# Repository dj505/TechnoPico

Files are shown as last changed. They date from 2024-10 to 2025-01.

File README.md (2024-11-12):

# TechnoPico
## An advanced, customizable, and universal 18-button dance game controller
---
## **This project is ongoing! It's not quite ready yet.
Check in later to see when it's ready for release! You can keep up on [my Discord server](https://discord.gg/ctMByBy) or by messaging me directly.
---

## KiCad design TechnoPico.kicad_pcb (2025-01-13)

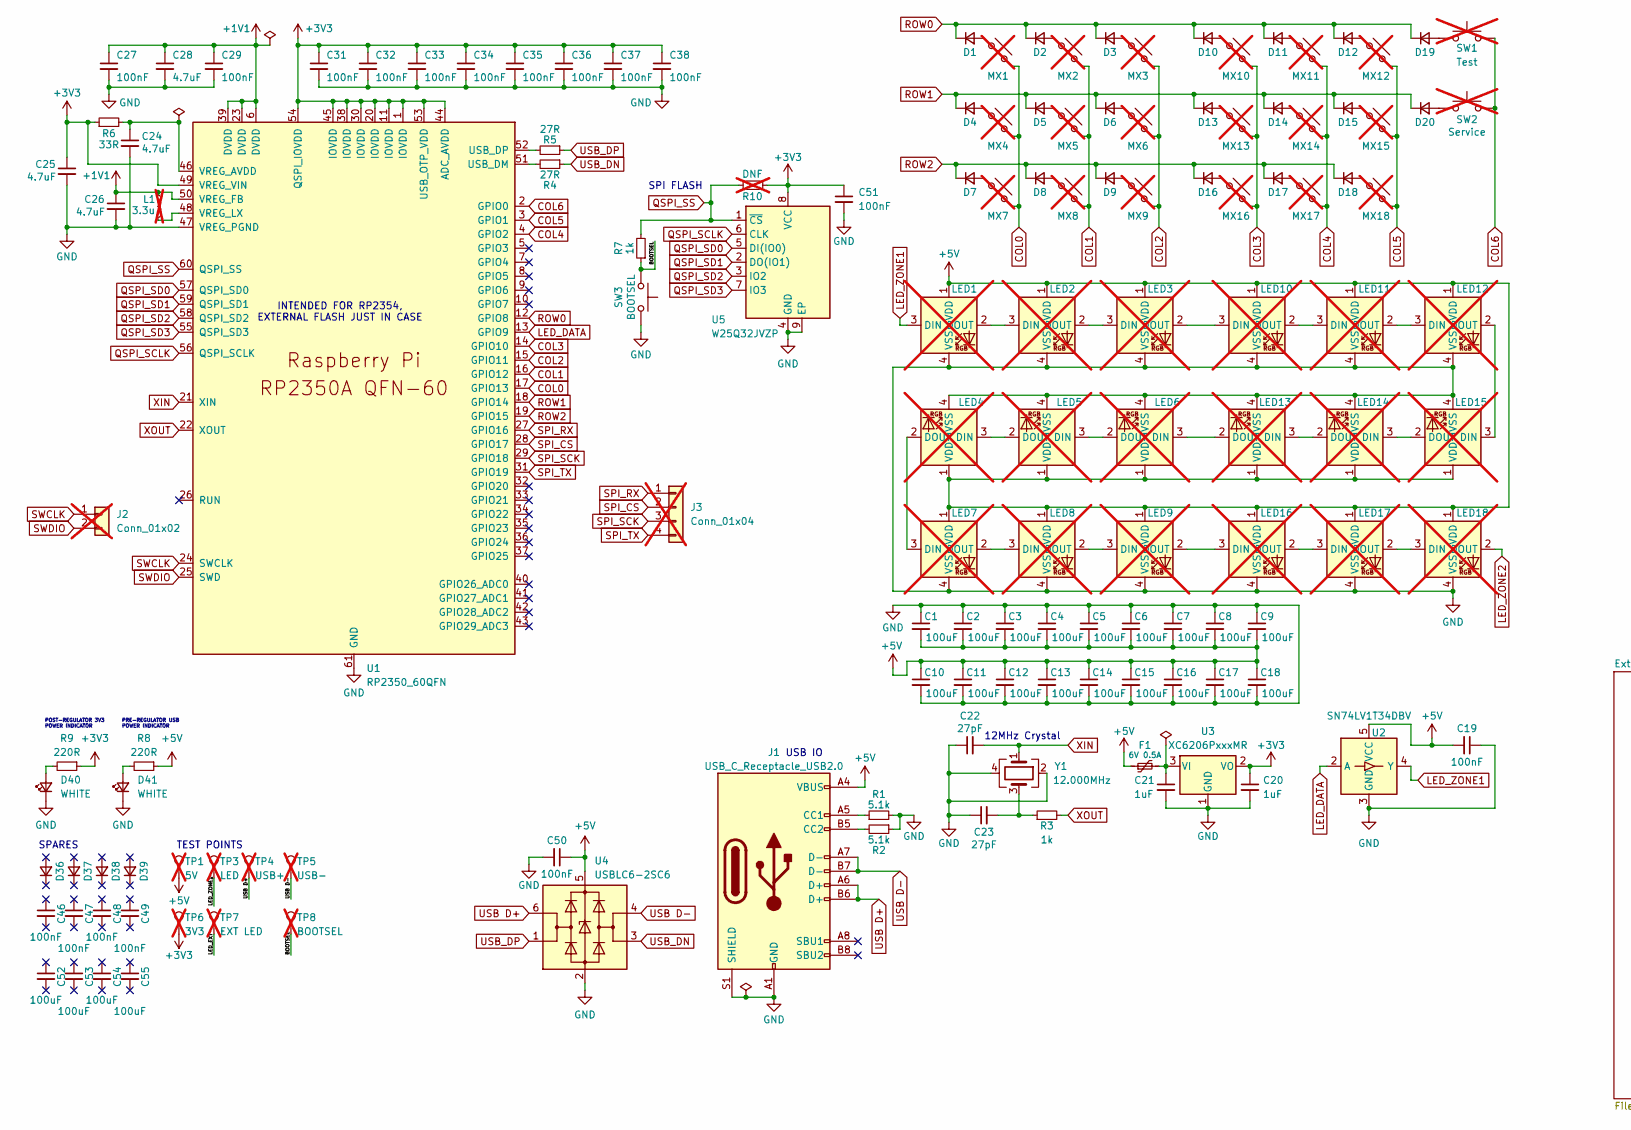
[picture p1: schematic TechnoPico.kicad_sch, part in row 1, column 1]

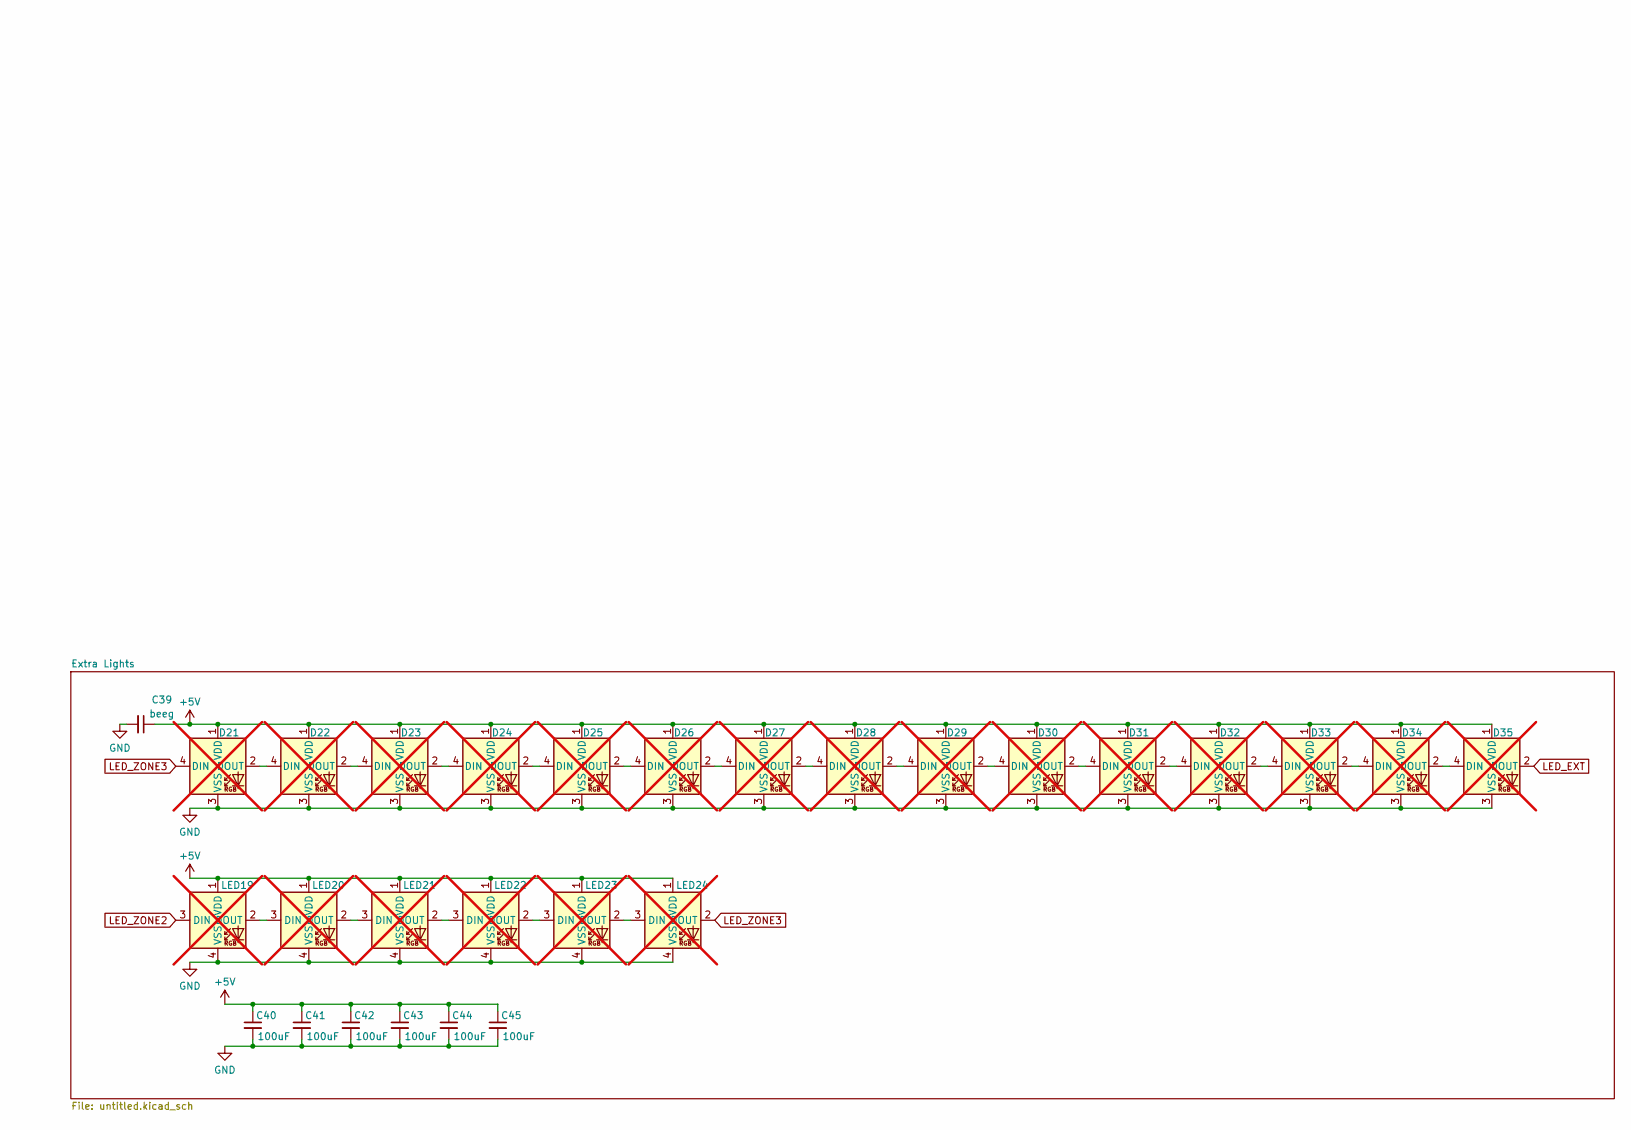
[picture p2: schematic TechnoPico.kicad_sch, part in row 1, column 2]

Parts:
C1, C2, C3, C4, C5, C6, C7, C8, C9, C10, C11, C12, C13, C14, C15, C16, C17, C18, C40, C41, C42, C43, C44, C45, C52, C53, C54, C55: 100uF; C_1206_3216Metric; LCSC C15008
C19, C27, C29, C31, C32, C33, C34, C35, C36, C37, C38, C46, C47, C48, C49, C50, C51: 100nF; C_0402_1005Metric; LCSC C1525
C20, C21: 1uF; C_0402_1005Metric; LCSC C52923
C22, C23: 27pF; C_0402_1005Metric; LCSC C1557
C24, C28: 4.7uF; C_0402_1005Metric; LCSC C274416
C25, C26: 4.7uF; C_0402_1005Metric_small_pads; LCSC C274416
C39: beeg; C_1206_3216Metric; LCSC C15008
D1, D2, D3, D4, D5, D6, D7, D8, D9, D10, D11, D12, D13, D14, D15, D16, D17, D18, D19, D20, D36, D37, D38, D39: SOD-123; D_SOD-123; LCSC C81598
D21, D22, D23, D24, D25, D26, D27, D28, D29, D30, D31, D32, D33, D34, D35: WS2812B; LED_WS2812B-2020_PLCC4_2.0x2.0mm; not fitted
D40, D41: WHITE; LED_0603_1608Metric; LCSC C2290
F1: 6V 0.5A; Fuse_0603_1608Metric; LCSC C69688
J1: USB_C_Receptacle_USB2.0; USB_C_Receptacle_G-Switch_GT-USB-7010ASV; LCSC C2988369
J2: Conn_01x02; PinSocket_1x02_P1.27mm_Vertical; not fitted
J3: Conn_01x04; PinHeader_1x04_P1.27mm_Vertical; not fitted
L1: 3.3u; L_pol_2016; not fitted
LED1, LED2, LED3, LED7, LED8, LED9, LED10, LED11, LED12, LED16, LED17, LED18: MX_SK6812MINI-E; LED_MX_6028R-ROT; not fitted
LED4, LED5, LED6, LED13, LED14, LED15: MX_SK6812MINI-E; LED_MX_6028R; not fitted
LED19, LED20, LED21, LED22, LED23, LED24: MX_SK6812MINI-E; LED_6028R; not fitted
MX1, MX2, MX3, MX4, MX5, MX6, MX7, MX8, MX9, MX10, MX11, MX12, MX13, MX14, MX15, MX16, MX17, MX18: MX_SW_HS; SW_MX_HS_CPG151101S11_1u; not fitted
R1, R2: 5.1k; R_0402_1005Metric; LCSC C25905
R3, R7: 1k; R_0402_1005Metric; LCSC C106235
R4, R5: 27R; R_0402_1005Metric; LCSC C2909343
R6: 33R; R_0402_1005Metric; LCSC C138002
R8, R9: 220R; R_0402_1005Metric; LCSC C112291
R10: DNF; R_0402_1005Metric_Pad0.72x0.64mm_HandSolder; not fitted
SW1: Test; SW_Tactile_SPST_Angled_PTS645Vx39-2LFS; not fitted
SW2: Service; SW_Tactile_SPST_Angled_PTS645Vx39-2LFS; not fitted
SW3: BOOTSEL; SW_Push_1P1T_XKB_TS-1187A; LCSC C318884
TP1: 5V; TestPoint_Pad_D1.0mm; not fitted
TP3: LED; TestPoint_Pad_D1.0mm; not fitted
TP4: USB+; TestPoint_Pad_D1.0mm; not fitted
TP5: USB-; TestPoint_Pad_D1.0mm; not fitted
TP6: 3V3; TestPoint_Pad_D1.0mm; not fitted
TP7: EXT LED; TestPoint_Pad_D1.0mm; not fitted
TP8: BOOTSEL; TestPoint_Pad_D1.0mm; not fitted
U1: RP2350_60QFN; RP2350-QFN-60-1EP_7x7_P0.4mm_EP3.4x3.4mm_ThermalVias; LCSC C42411118
U2: SN74LV1T34DBV; SOT-23-5; LCSC C100024
U3: XC6206PxxxMR; SOT-23-3; LCSC C5446
U4: USBLC6-2SC6; SOT-23-6; LCSC C2687116
U5: W25Q32JVZP; WSON-8-1EP_6x5mm_P1.27mm_EP3.4x4.3mm; LCSC C571260
Y1: 12.000MHz; Crystal_SMD_3225-4Pin_3.2x2.5mm; LCSC C20625731

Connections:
+1V1: C26.1, C27.1, C28.1, C29.1, L1.1, U1.6 (DVDD), U1.23 (DVDD), U1.39 (DVDD), U1.50 (VREG_FB)
+3V3: C20.1, C25.1, C31.1, C32.1, C33.1, C34.1, C35.1, C36.1, C37.1, C38.1, C51.1, R6.1, R9.1, R10.1, TP6.1, U1.1 (IOVDD), U1.11 (IOVDD), U1.20 (IOVDD), U1.30 (IOVDD), U1.38 (IOVDD), U1.44 (ADC_AVDD), U1.45 (IOVDD), U1.49 (VREG_VIN), U1.53 (USB_OTP_VDD), U1.54 (QSPI_IOVDD), U3.2 (VO), U5.8 (VCC)
+5V: C1.2, C2.2, C3.2, C4.2, C5.2, C6.2, C7.2, C8.2, C9.2, C10.1, C11.1, C12.1, C13.1, C14.1, C15.1, C16.1, C17.1, C18.1, C19.2, C39.1, C40.1, C41.1, C42.1, C43.1, C44.1, C45.1, C50.1, D21.1 (VDD), D22.1 (VDD), D23.1 (VDD), D24.1 (VDD), D25.1 (VDD), D26.1 (VDD), D27.1 (VDD), D28.1 (VDD), D29.1 (VDD), D30.1 (VDD), D31.1 (VDD), D32.1 (VDD), D33.1 (VDD), D34.1 (VDD), D35.1 (VDD), F1.1, J1.A4 (VBUS), J1.A9 (VBUS), J1.B4 (VBUS), J1.B9 (VBUS), LED1.1 (VDD), LED2.1 (VDD), LED3.1 (VDD), LED4.1 (VDD), LED5.1 (VDD), LED6.1 (VDD), LED7.1 (VDD), LED8.1 (VDD), LED9.1 (VDD), LED10.1 (VDD), LED11.1 (VDD), LED12.1 (VDD), LED13.1 (VDD), LED14.1 (VDD), LED15.1 (VDD), LED16.1 (VDD), LED17.1 (VDD), LED18.1 (VDD), LED19.1 (VDD), LED20.1 (VDD), LED21.1 (VDD), LED22.1 (VDD), LED23.1 (VDD), LED24.1 (VDD), R8.1, TP1.1, U2.5 (VCC), U4.5 (VBUS)
/BOOTSEL: R7.1, SW3.1, TP8.1
COL0: MX1.2, MX4.2, MX7.2, U1.17 (GPIO13)
COL1: MX2.2, MX5.2, MX8.2, U1.16 (GPIO12)
COL2: MX3.2, MX6.2, MX9.2, U1.15 (GPIO11)
COL3: MX10.2, MX13.2, MX16.2, U1.14 (GPIO10)
COL4: MX11.2, MX14.2, MX17.2, U1.4 (GPIO2)
COL5: MX12.2, MX15.2, MX18.2, U1.3 (GPIO1)
COL6: SW1.2, SW2.2, U1.2 (GPIO0)
GND: C1.1, C2.1, C3.1, C4.1, C5.1, C6.1, C7.1, C8.1, C9.1, C10.2, C11.2, C12.2, C13.2, C14.2, C15.2, C16.2, C17.2, C18.2, C19.1, C20.2, C21.2, C22.1, C23.1, C24.2, C25.2, C26.2, C27.2, C28.2, C29.2, C31.2, C32.2, C33.2, C34.2, C35.2, C36.2, C37.2, C38.2, C39.2, C40.2, C41.2, C42.2, C43.2, C44.2, C45.2, C50.2, C51.2, D21.3 (VSS), D22.3 (VSS), D23.3 (VSS), D24.3 (VSS), D25.3 (VSS), D26.3 (VSS), D27.3 (VSS), D28.3 (VSS), D29.3 (VSS), D30.3 (VSS), D31.3 (VSS), D32.3 (VSS), D33.3 (VSS), D34.3 (VSS), D35.3 (VSS), D40.1 (K), D41.1 (K), J1.A1 (GND), J1.A12 (GND), J1.B1 (GND), J1.B12 (GND), J1.S1 (SHIELD), LED1.4 (VSS), LED2.4 (VSS), LED3.4 (VSS), LED4.4 (VSS), LED5.4 (VSS), LED6.4 (VSS), LED7.4 (VSS), LED8.4 (VSS), LED9.4 (VSS), LED10.4 (VSS), LED11.4 (VSS), LED12.4 (VSS), LED13.4 (VSS), LED14.4 (VSS), LED15.4 (VSS), LED16.4 (VSS), LED17.4 (VSS), LED18.4 (VSS), LED19.4 (VSS), LED20.4 (VSS), LED21.4 (VSS), LED22.4 (VSS), LED23.4 (VSS), LED24.4 (VSS), R1.2, R2.1, SW3.2, U1.47 (VREG_PGND), U1.61 (GND), U2.3 (GND), U3.1 (GND), U4.2 (GND), U5.4 (GND), U5.9 (EP), Y1.2, Y1.4
LED_DATA: U1.13 (GPIO9), U2.2 (A)
LED_EXT: D35.2 (DOUT), TP7.1
LED_ZONE1: LED1.3 (DIN), TP3.1, U2.4 (Y)
LED_ZONE2: LED18.2 (DOUT), LED19.3 (DIN)
LED_ZONE3: D21.4 (DIN), LED24.2 (DOUT)
unnamed: C23.2, R3.1, Y1.3
unnamed: D1.2 (A), MX1.1
unnamed: D2.2 (A), MX2.1
unnamed: D3.2 (A), MX3.1
unnamed: D4.2 (A), MX4.1
unnamed: D5.2 (A), MX5.1
unnamed: D6.2 (A), MX6.1
unnamed: D7.2 (A), MX7.1
unnamed: D8.2 (A), MX8.1
unnamed: D9.2 (A), MX9.1
unnamed: D10.2 (A), MX10.1
unnamed: D11.2 (A), MX11.1
unnamed: D12.2 (A), MX12.1
unnamed: D13.2 (A), MX13.1
unnamed: D14.2 (A), MX14.1
unnamed: D15.2 (A), MX15.1
unnamed: D16.2 (A), MX16.1
unnamed: D17.2 (A), MX17.1
unnamed: D18.2 (A), MX18.1
unnamed: D19.2 (A), SW1.1
unnamed: D20.2 (A), SW2.1
unnamed: D21.2 (DOUT), D22.4 (DIN)
unnamed: D22.2 (DOUT), D23.4 (DIN)
unnamed: D23.2 (DOUT), D24.4 (DIN)
unnamed: D24.2 (DOUT), D25.4 (DIN)
unnamed: D25.2 (DOUT), D26.4 (DIN)
unnamed: D26.2 (DOUT), D27.4 (DIN)
unnamed: D27.2 (DOUT), D28.4 (DIN)
unnamed: D28.2 (DOUT), D29.4 (DIN)
unnamed: D29.2 (DOUT), D30.4 (DIN)
unnamed: D30.2 (DOUT), D31.4 (DIN)
unnamed: D31.2 (DOUT), D32.4 (DIN)
unnamed: D32.2 (DOUT), D33.4 (DIN)
unnamed: D33.2 (DOUT), D34.4 (DIN)
unnamed: D34.2 (DOUT), D35.4 (DIN)
unnamed: D40.2 (A), R9.2
unnamed: D41.2 (A), R8.2
unnamed: J1.A5 (CC1), R1.1
unnamed: J1.B5 (CC2), R2.2
unnamed: LED1.2 (DOUT), LED2.3 (DIN)
unnamed: LED2.2 (DOUT), LED3.3 (DIN)
unnamed: LED4.3 (DIN), LED5.2 (DOUT)
unnamed: LED4.2 (DOUT), LED7.3 (DIN)
unnamed: LED5.3 (DIN), LED6.2 (DOUT)
unnamed: LED7.2 (DOUT), LED8.3 (DIN)
unnamed: LED8.2 (DOUT), LED9.3 (DIN)
unnamed: LED3.2 (DOUT), LED10.3 (DIN)
unnamed: LED10.2 (DOUT), LED11.3 (DIN)
unnamed: LED11.2 (DOUT), LED12.3 (DIN)
unnamed: LED12.2 (DOUT), LED15.3 (DIN)
unnamed: LED13.3 (DIN), LED14.2 (DOUT)
unnamed: LED6.3 (DIN), LED13.2 (DOUT)
unnamed: LED14.3 (DIN), LED15.2 (DOUT)
unnamed: LED9.2 (DOUT), LED16.3 (DIN)
unnamed: LED16.2 (DOUT), LED17.3 (DIN)
unnamed: LED17.2 (DOUT), LED18.3 (DIN)
unnamed: LED19.2 (DOUT), LED20.3 (DIN)
unnamed: LED20.2 (DOUT), LED21.3 (DIN)
unnamed: LED21.2 (DOUT), LED22.3 (DIN)
unnamed: LED22.2 (DOUT), LED23.3 (DIN)
unnamed: LED23.2 (DOUT), LED24.3 (DIN)
unnamed: R4.2, U1.51 (USB_DM)
unnamed: R5.2, U1.52 (USB_DP)
unnamed: C24.1, R6.2, U1.46 (VREG_AVDD)
unnamed: L1.2, U1.48 (VREG_LX)
unnamed: C21.1, F1.2, U3.3 (VI)
QSPI_SCLK: U1.56 (QSPI_SCLK), U5.6 (CLK)
QSPI_SD0: U1.57 (QSPI_SD0), U5.5 (DI(IO0))
QSPI_SD1: U1.59 (QSPI_SD1), U5.2 (DO(IO1))
QSPI_SD2: U1.58 (QSPI_SD2), U5.3 (IO2)
QSPI_SD3: U1.55 (QSPI_SD3), U5.7 (IO3)
QSPI_SS: R7.2, R10.2, U1.60 (QSPI_SS), U5.1 (~CS)
ROW0: D1.1 (K), D2.1 (K), D3.1 (K), D10.1 (K), D11.1 (K), D12.1 (K), D19.1 (K), U1.12 (GPIO8)
ROW1: D4.1 (K), D5.1 (K), D6.1 (K), D13.1 (K), D14.1 (K), D15.1 (K), D20.1 (K), U1.18 (GPIO14)
ROW2: D7.1 (K), D8.1 (K), D9.1 (K), D16.1 (K), D17.1 (K), D18.1 (K), U1.19 (GPIO15)
SPI_CS: J3.2, U1.28 (GPIO17)
SPI_RX: J3.1, U1.27 (GPIO16)
SPI_SCK: J3.3, U1.29 (GPIO18)
SPI_TX: J3.4, U1.31 (GPIO19)
SWCLK: J2.1, U1.24 (SWCLK)
SWDIO: J2.2, U1.25 (SWD)
USB D+: J1.A6 (D+), J1.B6 (D+), TP4.1, U4.6 (I/O1)
USB D-: J1.A7 (D-), J1.B7 (D-), TP5.1, U4.4 (I/O2)
USB_DN: R4.1, U4.3 (I/O2)
USB_DP: R5.1, U4.1 (I/O1)
XIN: C22.2, U1.21 (XIN), Y1.1
XOUT: R3.2, U1.22 (XOUT)

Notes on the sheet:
SPI FLASH
PRE-REGULATOR USB POWER INDICATOR
INTENDED FOR RP2354, EXTERNAL FLASH JUST IN CASE
12MHz Crystal
USB IO
POST-REGULATOR 3V3 POWER INDICATOR
TEST POINTS
SPARES

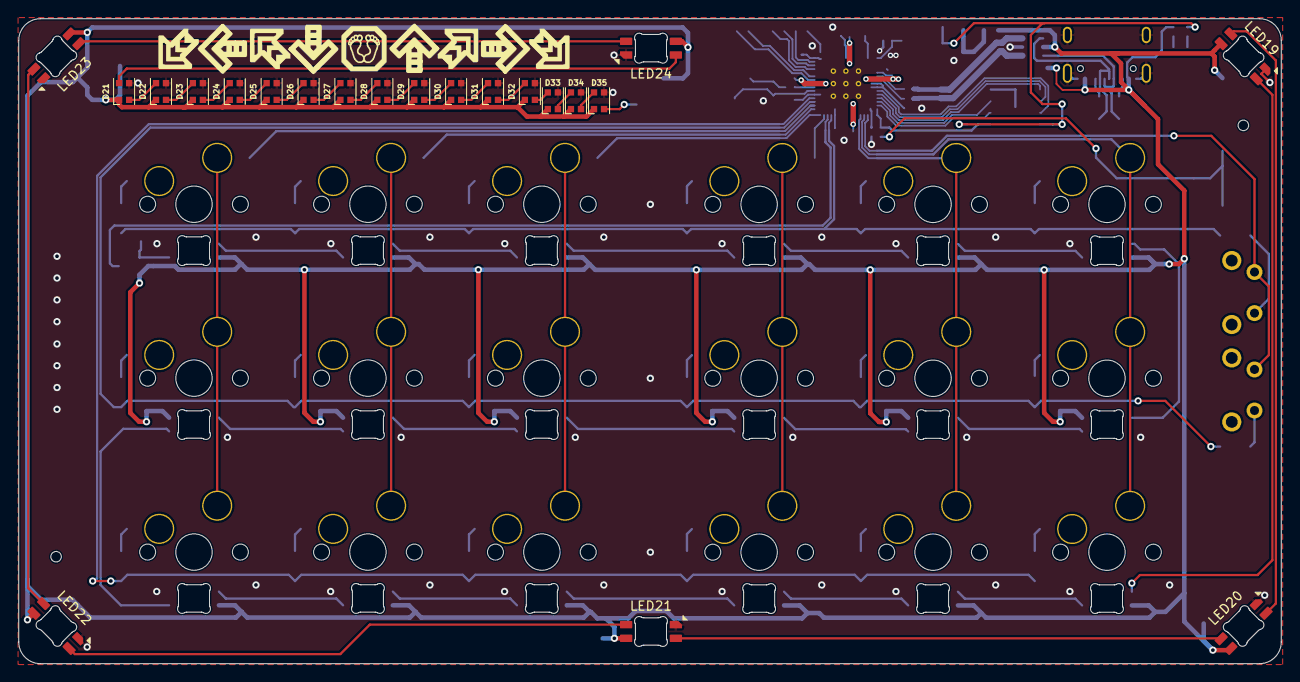
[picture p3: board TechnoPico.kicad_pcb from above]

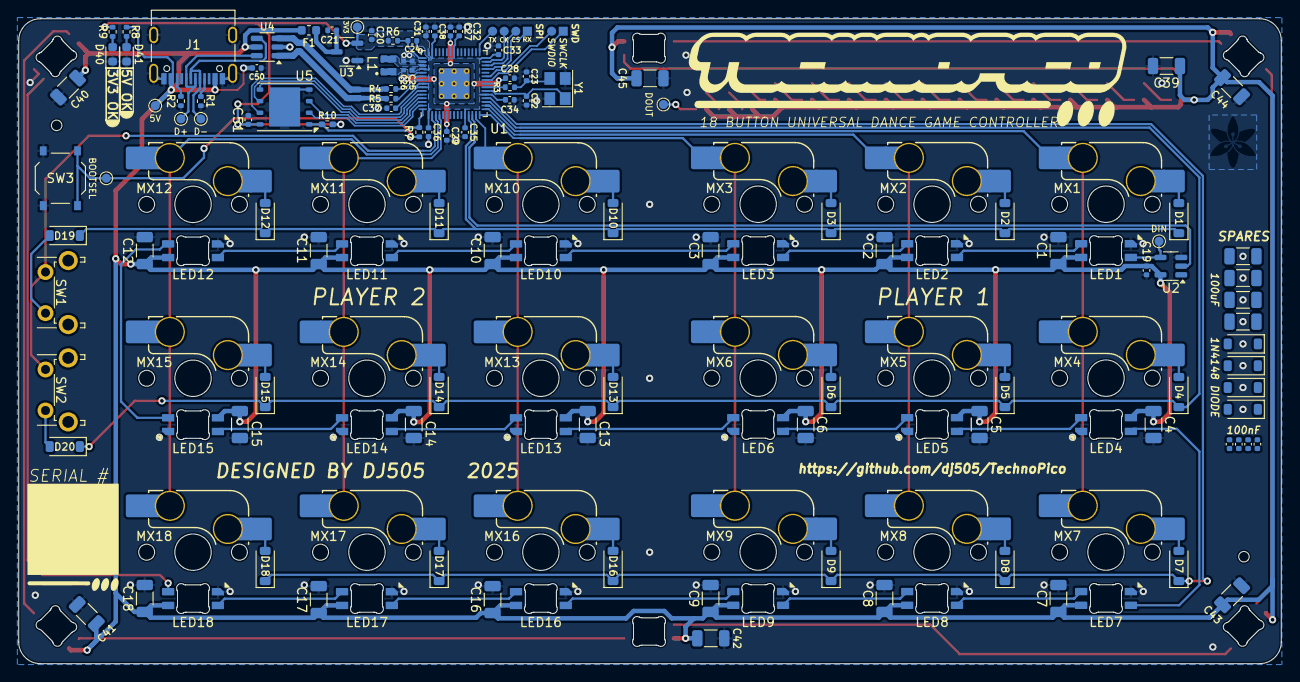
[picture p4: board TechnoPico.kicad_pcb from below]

Board: 2 copper layers, 138.3 x 70.6 mm, 168 parts (147 on the bottom side), 104 nets.

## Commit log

2024-10-29 Initial commit (oops already made the whole thing)
    [TechnoPico-Plate.kicad_pcb, TechnoPico-Plate.kicad_sch, TechnoPico.kicad_pcb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]
2024-10-30 Experimental corner cutouts for mounting
    [TechnoPico.kicad_pcb, TechnoPico.kicad_sch]
2024-10-30 Revert main PCB corner cutouts, add holes to plate
    [TechnoPico-Plate.kicad_pcb, TechnoPico.kicad_pcb]
2025-01-12 Add flash
    [TechnoPico.kicad_pcb, TechnoPico.kicad_sch]
2025-01-12 Reroute 5V to LEDs to split up the ground plane less, etc
    [TechnoPico.kicad_pcb, TechnoPico.kicad_sch, untitled.kicad_sch]
2025-01-12 Finishing touches
    [TechnoPico.kicad_pcb, TechnoPico.kicad_sch, untitled.kicad_sch]
2025-01-13 Routing changes, use custom RP2350 inductor, etc
    [TechnoPico.kicad_pcb, TechnoPico.kicad_sch, untitled.kicad_sch]
